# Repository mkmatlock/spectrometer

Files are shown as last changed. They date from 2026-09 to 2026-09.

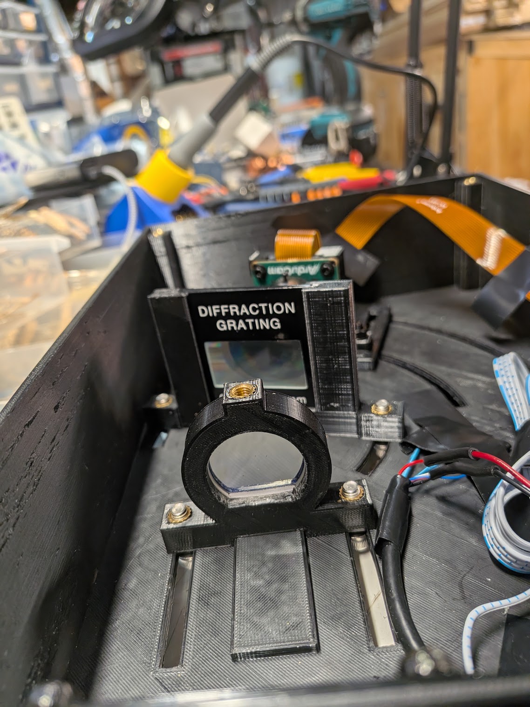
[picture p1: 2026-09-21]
images/build_axis.jpg

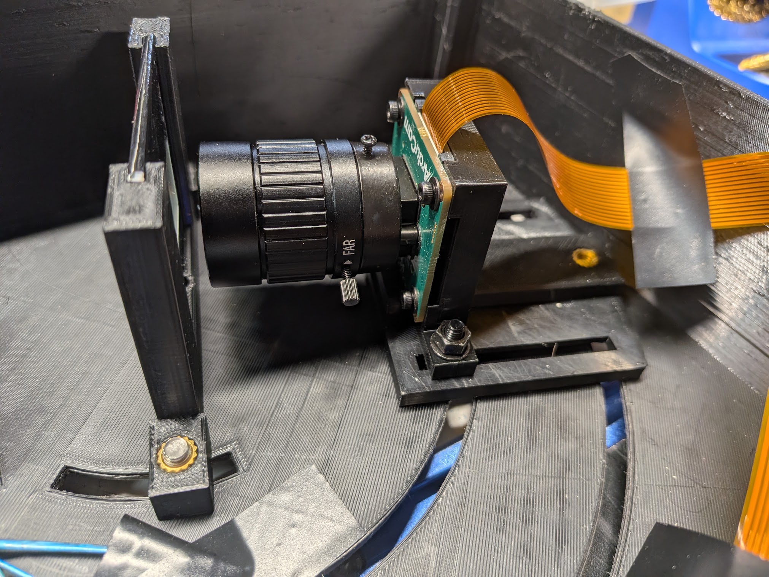
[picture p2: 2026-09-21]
images/build_camera.jpg

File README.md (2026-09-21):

# Raspberry pi configuration

First, we need to disable the activity light to eliminate a source of stray light and add an overlay to use the external LED as a power indicator.

Edit `/boot/firmware/config.txt`, find the `[all]` section heading and add:

```ini
[all]
dtparam=act_led_trigger=none
dtoverlay=gpio-led,gpio=26,label=power,trigger=default-on
```

Reboot with `sudo reboot` to apply.

Next, enable SPI and I2C in `sudo raspi-config` and reboot if prompted. The runtime user
needs access to the `spi`, `i2c`, and `gpio` groups.

Finally, hook up the waveshare device according to instructions [here](https://www.waveshare.com/wiki/3.5inch_Capacitive_Touch_LCD).

# Install the software

Fill out the dotenv:

```vi .env
HOST="RPI_IP_ADDRESS"
USER="RPI_USERNAME"
PORT="22"
```

# Run the spectrometer software

Install the distribution package on the Pi:

```sh
sudio ./setup.sh
```

This will start a systemd service spectrometer.service that will keep the spectrometer app running in the background at all times. 

## Raspberry Pi OS Lite hardware setup

The supplied drivers use BCM pins 27 (LCD reset), 25 (LCD data/command), 18
(backlight), 4 (touch interrupt), and 17 (touch reset), in addition to the SPI and
I2C bus pins. Wiring must match these assignments. Do not run another display
service or framebuffer driver that owns the same SPI device or GPIO pins.

Rendering passes Pygame RGB buffers directly to the LCD driver's RGB565
conversion. Camera acquisition starts by default. Use Raspberry
Pi OS Bookworm or later and install the updated dependencies with `setup.sh`.
Stop any separate camera server before starting this app; only one process can
own the camera.

```sh
python3 -m spectrometer --fps 5 --frame-averaging 3 --exposure-us 20000
```

Settings are loaded from `~/.spectrometer_config` on startup; the file is created
with defaults (5 fps, three-frame averaging, 4056×3040, automatic exposure) when absent. Camera settings,
calibration labels, and the sensor bounding box persist between runs. `--fps` and
`--frame-averaging`, and `--exposure-us` save new values; use `--auto-exposure` to restore automatic exposure.

Full-resolution IMX477 capture is
limited to about 10 fps; the requested rate is capped to the sensor mode's limit.
Fixed exposures are clamped to the sensor limits and frame period. Startup logs report the configured frame
period and first-frame exposure. Use `--no-camera` for touch-only diagnostics or
`--windowed --no-camera` for a desktop preview without Pi hardware.

## REST API

Open `http://<pi-address>:8000/` for the browser interface: review, rename,
delete, display modes, capture, and read-only settings. No frontend build or
internet connection is required. Capture requires the camera to be running.
The same service provides the API below.
`python3 -m spectrometer.server` runs the web interface and API without a camera.
Spectrum IDs are integer timestamps in milliseconds since the Unix epoch.

### GET /capture?name=<name>

Saves a spectrum locally and returns its ID as a JSON integer after saving.
Provide one URL-encoded name of 1–64 characters, for example
`/capture?name=My%20spectrum`.

Returns 400 for an invalid name, 409 when the camera is paused or busy, 503
when no camera is attached, or 500 on capture failure. A 504 means the request
timed out; the capture may still finish saving.

### GET /list

Returns a JSON array of saved spectra, newest first. Each entry contains `id`,
`name`, and `timestamp` formatted as `YYYY-MM-dd HH:mm:ss`. Returns `[]` when
there are no captures. Older unnamed captures use `Unnamed spectrum`;
unreadable files are skipped.
Metadata is kept in a rebuildable `.spectrometer_index.sqlite3` catalog beside
the captures. Existing captures are read once when first indexed; later lists do
not deserialize their raw camera images.

### GET /spectrum/<id>

Returns the full saved spectrum as JSON, including `filename`, name, timestamp,
instrument settings, saved calibration, intensities, sensor area, and image data.
Timestamps use ISO 8601; intensities are arrays; calibration pixel keys are
strings. Binary image data uses base64, with `dtype` and `shape` also included
for `averaged_camera_output` (the cropped BGR image). `spectrum_maximum` stores
the plot's intensity limit. Returns 404 for an unknown ID or 500 if the matching
spectrum data cannot be returned.
Only one full-spectrum transfer is processed at a time; another concurrent
transfer returns 503 to protect memory on the Pi Zero.

### DELETE /spectrum/<id>

Deletes the corresponding saved file. Returns 204 with an empty body on success,
404 for an unknown ID, or 500 if deletion fails.

### PATCH /spectrum/<id>

Renames a spectrum. Send `Content-Type: application/json` and `{"name":"New name"}`
(1–64 characters). Returns `{"id":123,"name":"New name"}`; the ID and recorded
data are preserved. Returns 400 for an invalid name, 404 for an unknown ID,
or 503 if another spectrum operation is in progress.

### GET /settings

Returns the current saved configuration and network status as a JSON object:

- `camera`: `frame_rate`, `frame_averaging`, `resolution`, and `exposure_us` (`"min"`/`"max"` follow the exposure limits; `null` means automatic).
- `calibration`: `scale` pixel/value pairs, `sensor_area`, and `channel_ranges`.
- `network`: `ip_address` and `wifi_ssid` (refreshed in the background).

## Touch diagnostics

```sh
python3 -m spectrometer --touch-debug
```

Touch and release each button. Logs show raw controller coordinates, mapped UI coordinates, releases, and placeholder button actions. Button centers are approximately `(82, 288)`, `(240, 288)`, and `(397, 288)`. If there are no touch logs, the controller is not reporting contacts; if mapped coordinates miss these locations, the panel needs a different coordinate mapping. Exit with Ctrl+C, then run `sudo systemctl start spectrometer` to restore the service.

Use `python3 -m spectrometer --performance-debug` to report rolling camera,
rendering, LCD, and metadata timings every five seconds without per-frame logs.

## Power button

Connect the momentary switch between GPIO 21 (physical pin 40) and GND. The app
enables the internal pull-up and debounces the switch. A short press toggles the
backlight and camera/UI activity on release. Hold for three seconds to open a
shutdown confirmation; Yes shuts down the Pi, and No returns to the application.
Run the updated `setup.sh` once to install the shutdown permission. The Pi remains
running. Pending captures are cancelled on pause; files already being written
finish saving. Press again to resume. This applies to the hardware UI.

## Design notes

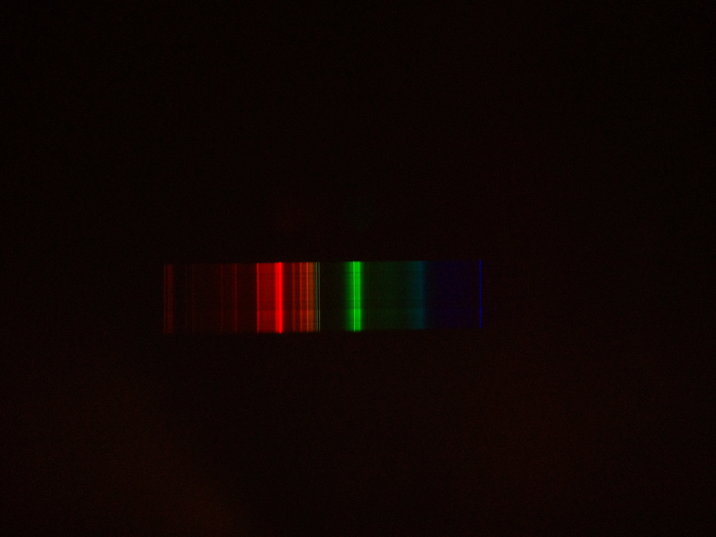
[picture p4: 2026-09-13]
images/cfl.png

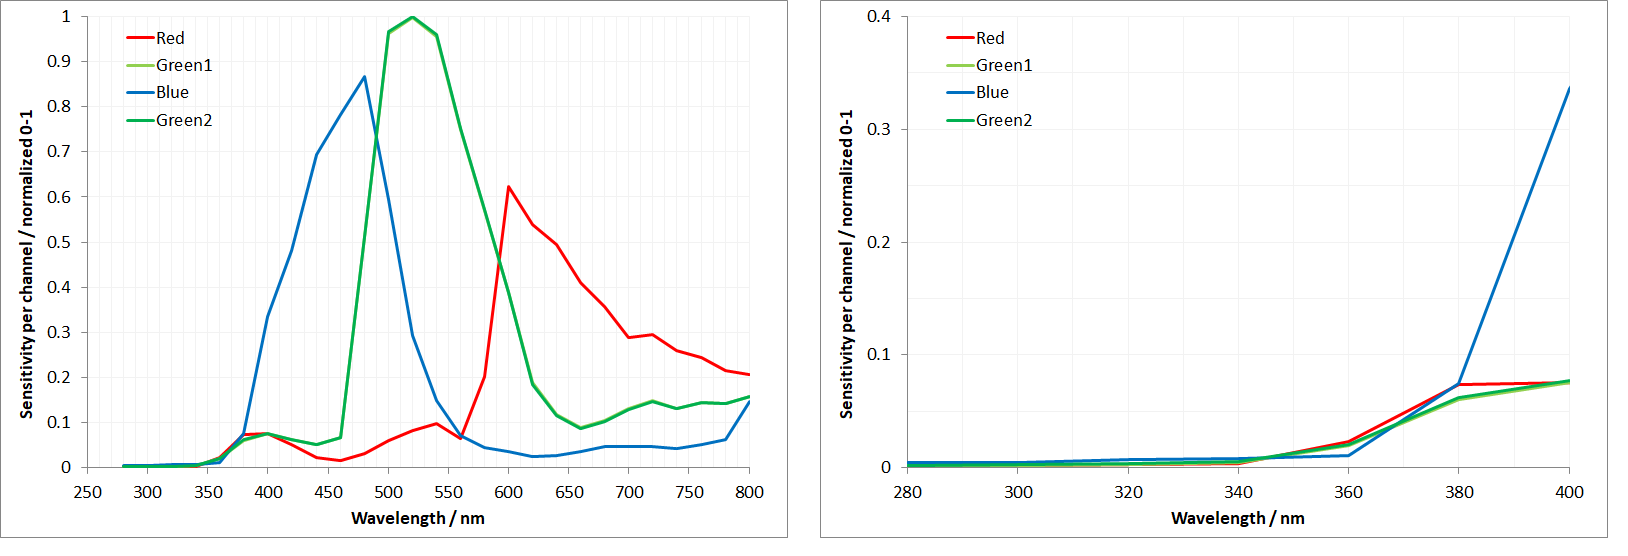
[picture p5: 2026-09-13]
images/IMX477_sensitivity.png

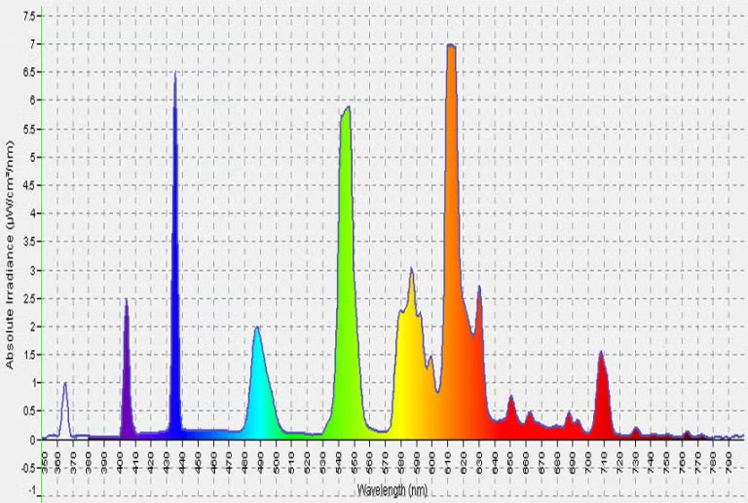
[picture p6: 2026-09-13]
images/reference.png

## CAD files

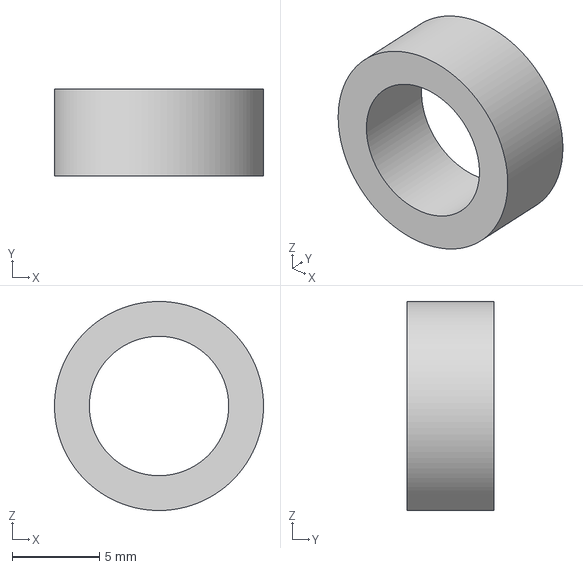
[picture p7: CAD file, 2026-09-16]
models/Slit Bushing.3mf
12.0 x 5.00 x 12.0 mm

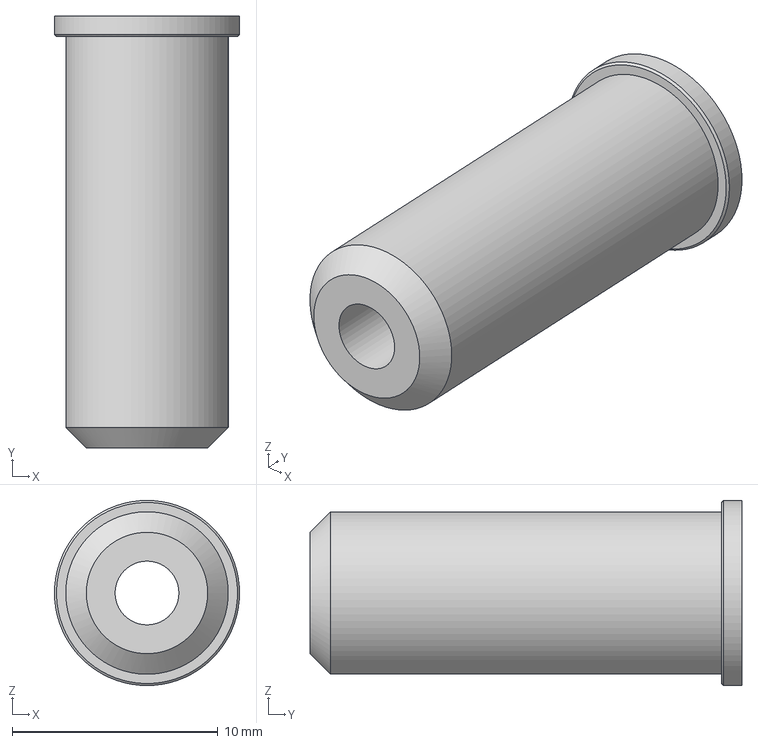
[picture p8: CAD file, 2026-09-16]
models/Slit Spring.3mf
9.00 x 21.0 x 9.00 mm

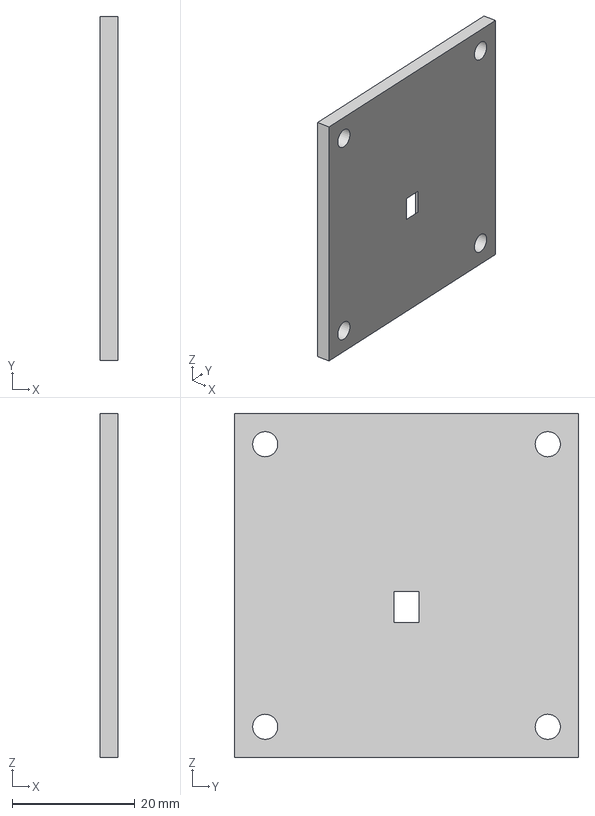
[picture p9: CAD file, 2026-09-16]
models/Slit Inner Cover.3mf
3.00 x 56.0 x 56.0 mm

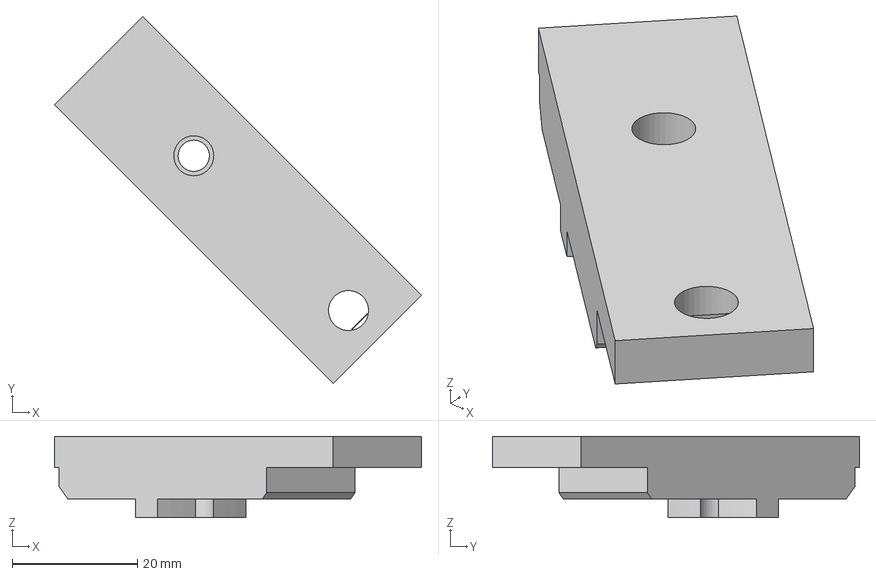
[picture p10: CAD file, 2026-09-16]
models/Camera Slide.3mf
58.7 x 58.7 x 13.0 mm

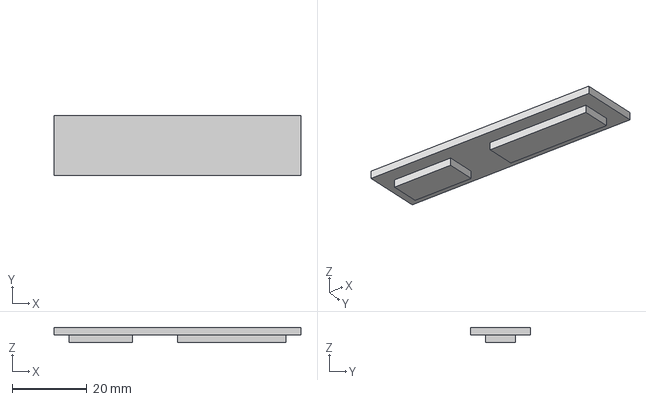
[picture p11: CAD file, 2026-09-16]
models/Port Cover.3mf
66.0 x 16.0 x 4.00 mm

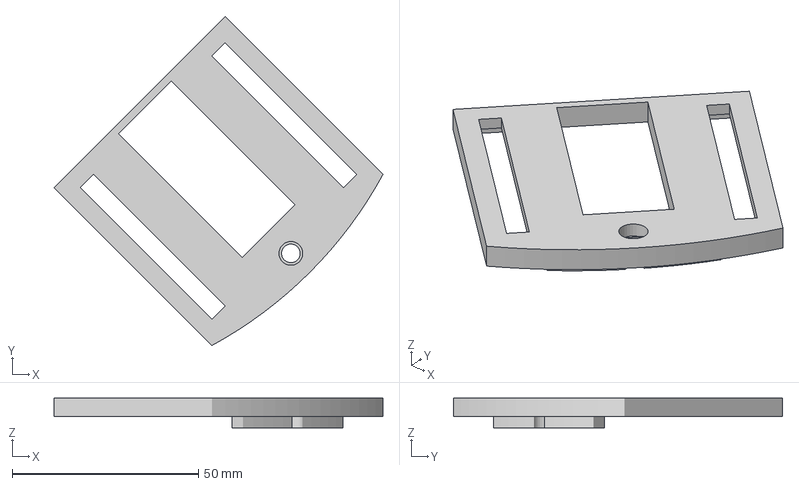
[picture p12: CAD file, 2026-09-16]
models/Camera Rotation.3mf
88.4 x 88.4 x 8.00 mm

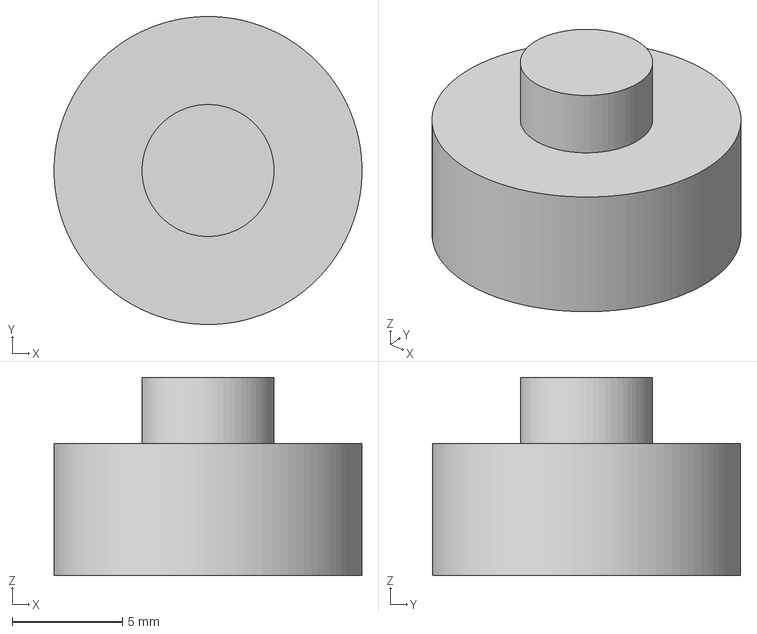
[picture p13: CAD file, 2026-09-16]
models/Foot.3mf
14.0 x 14.0 x 9.00 mm

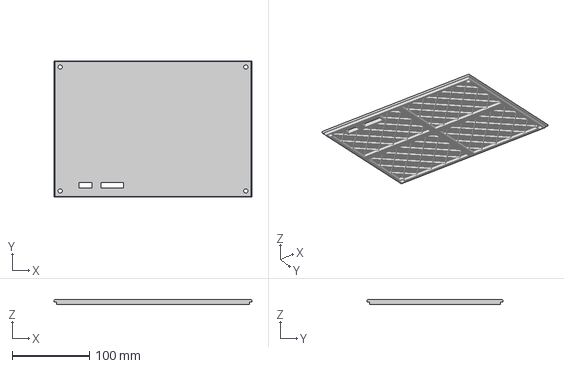
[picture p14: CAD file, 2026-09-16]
models/Lid.3mf
256.0 x 176.0 x 6.00 mm

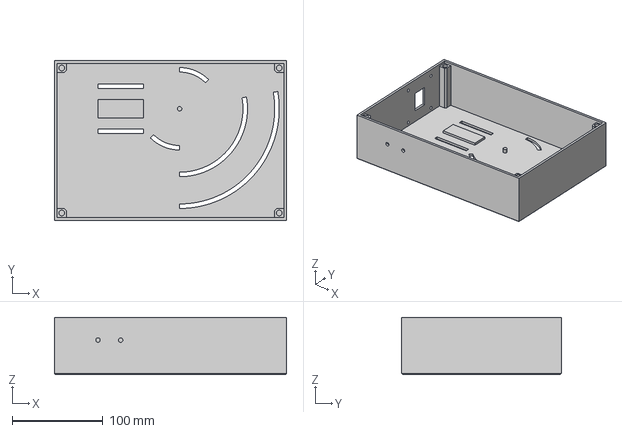
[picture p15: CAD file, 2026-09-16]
models/Enclosure.3mf
256.0 x 176.0 x 63.0 mm

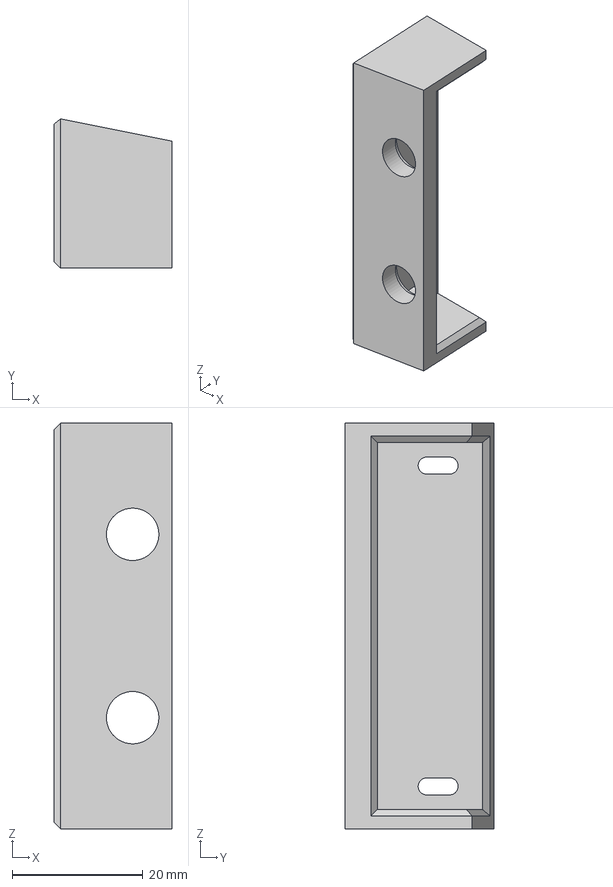
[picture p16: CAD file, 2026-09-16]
models/Slit Aperture.3mf
18.0 x 22.8 x 62.0 mm

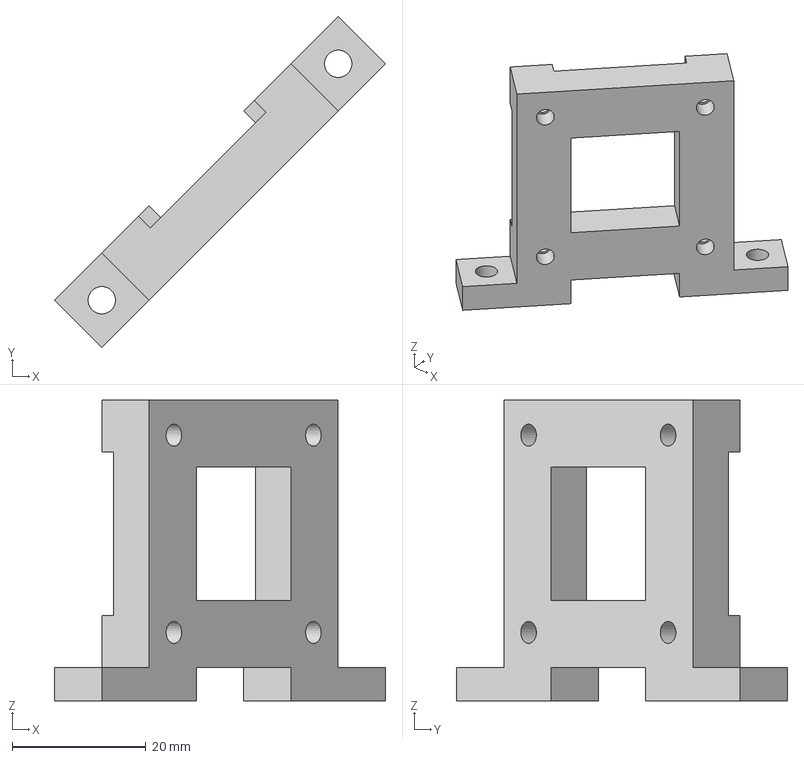
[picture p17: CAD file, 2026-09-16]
models/Camera Mount.3mf
49.5 x 49.5 x 45.0 mm

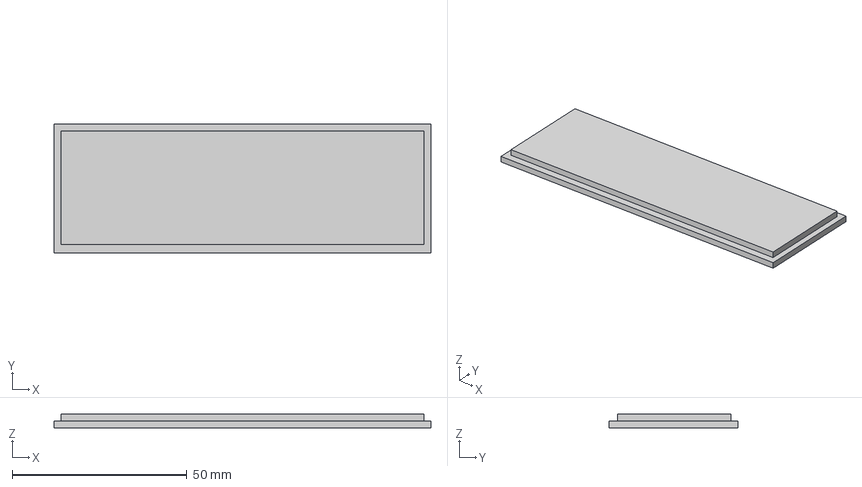
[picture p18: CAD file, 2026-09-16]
models/Interface Cover.3mf
108.0 x 37.0 x 4.00 mm

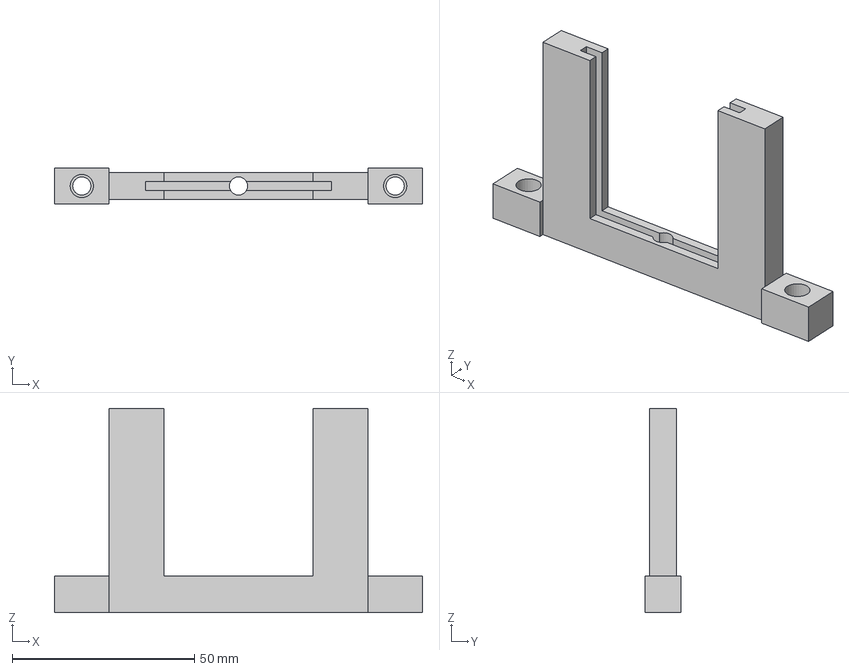
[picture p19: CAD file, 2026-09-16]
models/Diffractor.3mf
101.0 x 10.0 x 56.0 mm

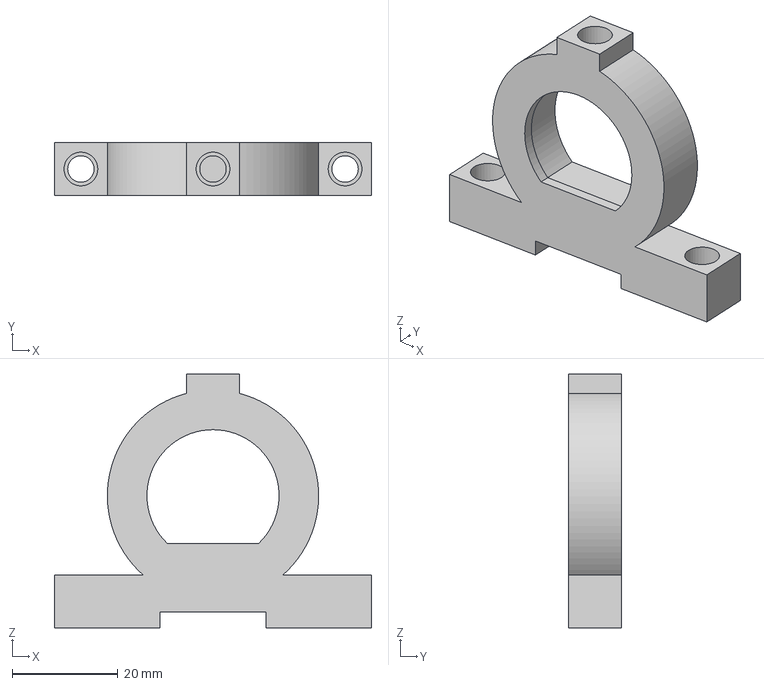
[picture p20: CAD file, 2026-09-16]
models/Collumnator.3mf
60.0 x 10.0 x 48.0 mm

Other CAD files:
models/Slit Stabilizer.3mf
models/Slit Mount.3mf
models/Microcontroller.3mf
models/Interface.3mf
schematics/PiZero.f3d
schematics/Spectrometer.f3z

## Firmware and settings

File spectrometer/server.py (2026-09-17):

"""Device-hosted spectrum viewer and spectrometer REST API."""

import argparse
from copy import deepcopy
import base64
from concurrent.futures import TimeoutError
from datetime import datetime
from pathlib import Path
import pickle
from contextlib import contextmanager
from http.client import HTTPConnection
from http.server import BaseHTTPRequestHandler, ThreadingHTTPServer
import json
import logging
import re
import threading
from urllib.parse import urlsplit, parse_qs

from .catalog import DuplicateSpectrumID, SpectrumCatalog, timestamp_id
from .capture import delete_capture, rename_capture, update_peak_label
from .settings import network_status


LOGGER = logging.getLogger(__name__)
WEB_DIRECTORY = Path(__file__).with_name('web')
STATIC_FILES = {
    '/': ('index.html', 'text/html; charset=utf-8'),
    '/app.js': ('app.js', 'text/javascript; charset=utf-8'),
    '/style.css': ('style.css', 'text/css; charset=utf-8'),
    '/spectrum-math.js': ('spectrum-math.js', 'text/javascript; charset=utf-8'),
    '/annotations.js': ('annotations.js', 'text/javascript; charset=utf-8'),
}
RESPONSE_CHUNK_SIZE = 64 * 1024


def json_value(value):
    if isinstance(value, datetime):
        return value.isoformat()
    if isinstance(value, bytes):
        return {'encoding': 'base64', 'data': base64.b64encode(value).decode('ascii')}
    if hasattr(value, 'tolist'):
        return value.tolist()
    raise TypeError(f'Cannot encode {type(value).__name__}')


def spectrum_response(path, record):
    """Full JSON representation of a saved spectrum."""
    result = dict(record, filename=path.name)
    image = record['averaged_camera_output']
    result['averaged_camera_output'] = {
        'encoding': 'base64', 'dtype': str(image.dtype), 'shape': list(image.shape),
        'data': base64.b64encode(image.tobytes()).decode('ascii')}
    return result


class APIHandler(BaseHTTPRequestHandler):
    timeout = 10

    def capture(self):
        query = parse_qs(urlsplit(self.path).query, keep_blank_values=True)
        names = query.get('name', [])
        if set(query) != {'name'} or len(names) != 1 or not 1 <= len(names[0].strip()) <= 64:
            self._respond({'error': 'Provide one name of 1–64 characters'}, 400)
            return
        camera = self.server.camera
        if camera is None:
            self._respond({'error': 'Camera unavailable'}, 503)
            return
        future = camera.request_api_capture(names[0].strip())
        if future is None:
            self._respond({'error': 'Camera paused or capture busy'}, 409)
            return
        try:
            _, record = future.result(timeout=120)
            self._respond(timestamp_id(record["timestamp"]))
        except TimeoutError:
            self._respond({'error': 'Capture timed out; it may still finish saving'}, 504)
        except (BrokenPipeError, ConnectionResetError):
            LOGGER.info('Capture saved; client disconnected')
        except Exception:
            LOGGER.exception('API capture failed')
            self._respond({'error': 'Capture failed'}, 500)

    def list(self):
        return self.server.catalog.list_api()

    def _find_spectrum(self, spectrum_id):
        path = self.server.catalog.find(spectrum_id)
        if path is None:
            return None
        try:
            with path.open('rb') as source:
                return path, pickle.load(source)
        except FileNotFoundError:
            self.server.catalog.remove(path.name)
            return None

    def spectrum(self, spectrum_id):
        if not self.server.raw_slots.acquire(blocking=False):
            self._respond({'error': 'Another spectrum transfer is in progress'}, 503)
            return
        try:
            try:
                found = self._find_spectrum(spectrum_id)
            except DuplicateSpectrumID:
                self._respond({'error': 'Spectrum ID is ambiguous'}, 409)
                return
            except Exception:
                LOGGER.exception('Cannot load spectrum %s', spectrum_id)
                self._respond({'error': 'Cannot read spectrum data'}, 500)
                return
            if found is None:
                self._respond({'error': 'Spectrum not found'}, 404)
                return
            path, record = found
            try:
                self._respond(spectrum_response(path, record))
            except (BrokenPipeError, ConnectionResetError):
                LOGGER.info('Client disconnected during download')
            except Exception:
                LOGGER.exception('Cannot read spectrum %s', path.name)
                self._respond({'error': 'Cannot read spectrum data'}, 500)
        finally:
            self.server.raw_slots.release()

    def delete_spectrum(self, spectrum_id):
        if not self.server.raw_slots.acquire(blocking=False):
            self._respond({'error': 'Another spectrum operation is in progress'}, 503)
            return
        try:
            self._delete_spectrum(spectrum_id)
        finally:
            self.server.raw_slots.release()

    def _delete_spectrum(self, spectrum_id):
        try:
            path = self.server.catalog.find(spectrum_id)
        except DuplicateSpectrumID:
            self._respond({'error': 'Spectrum ID is ambiguous'}, 409)
            return
        if path is None:
            self._respond({'error': 'Spectrum not found'}, 404)
            return
        try:
            delete_capture(path)
        except FileNotFoundError:
            self._respond({'error': 'Spectrum not found'}, 404)
        except OSError:
            LOGGER.exception('Cannot delete spectrum %s', path.name)
            self._respond({'error': 'Cannot delete spectrum'}, 500)
        else:
            self.server.catalog.remove(path.name)
            self.send_response(204)
            self.end_headers()

    def update_spectrum(self, spectrum_id):
        if self.headers.get_content_type() != 'application/json':
            self._respond({'error': 'Expected application/json'}, 415)
            return
        try:
            length = int(self.headers.get('Content-Length', '0'))
            if not 0 < length <= 4096 or self.headers.get('Transfer-Encoding'):
                raise ValueError('Invalid body length')
            payload = json.loads(self.rfile.read(length))
            if isinstance(payload, dict) and set(payload) == {'name'}:
                name = payload['name']
                if not isinstance(name, str) or not 1 <= len(name.strip()) <= 64:
                    raise ValueError('Invalid name')
                operation = 'rename'
            elif isinstance(payload, dict) and set(payload) == {'peak_label'}:
                annotation = payload['peak_label']
                if not isinstance(annotation, dict) or set(annotation) != {'pixel', 'label'}:
                    raise ValueError('Invalid peak label')
                pixel, label = annotation['pixel'], annotation['label']
                if type(pixel) is not int or (label is not None and
                        (not isinstance(label, str) or not 1 <= len(label.strip()) <= 64)):
                    raise ValueError('Invalid peak label')
                operation = 'label'
            else:
                raise ValueError('Invalid spectrum update')
        except (ValueError, UnicodeDecodeError, RecursionError):
            self._respond({'error': 'Provide a name of 1–64 characters or a peak_label '
                           'with an integer pixel and a label of 1–64 characters (null to delete)'}, 400)
            return
        if not self.server.raw_slots.acquire(blocking=False):
            self._respond({'error': 'Another spectrum operation is in progress'}, 503)
            return
        try:
            try:
                path = self.server.catalog.find(spectrum_id)
            except DuplicateSpectrumID:
                self._respond({'error': 'Spectrum ID is ambiguous'}, 409)
                return
            except Exception:
                LOGGER.exception('Cannot find spectrum %s for %s', spectrum_id, operation)
                self._respond({'error': 'Cannot read spectrum metadata'}, 500)
                return
            if path is None:
                self._respond({'error': 'Spectrum not found'}, 404)
                return
            try:
                if operation == 'rename':
                    result = {'name': rename_capture(path, name)}
                else:
                    try:
                        result = {'peak_labels': update_peak_label(path, pixel, label)}
                    except ValueError as exc:
                        self._respond({'error': str(exc)}, 400)
                        return
                # Usually a metadata-only check: the mutation already updates
                # SQLite. Also refresh this instance's in-memory fallback index.
                self.server.catalog.reconcile_paths([path])
            except FileNotFoundError:
                self.server.catalog.remove(path.name)
                self._respond({'error': 'Spectrum not found'}, 404)
                return
            except Exception:
                LOGGER.exception('Cannot %s spectrum %s', operation, path.name)
                self._respond({'error': 'Cannot ' + operation + ' spectrum'}, 500)
                return
            self._respond({'id': int(spectrum_id), **result})
        finally:
            self.server.raw_slots.release()

    def settings(self):
        from .config import SettingsStore
        store = self.server.settings_store
        if store is None:
            # Standalone API reads the same persistent configuration as the UI.
            store = SettingsStore()
        result = deepcopy(store.data)
        result['network'] = dict(self.server.network_settings)
        return result

    def static_file(self, path):
        filename, content_type = STATIC_FILES[path]
        try:
            data = (WEB_DIRECTORY / filename).read_bytes()
        except OSError:
            LOGGER.exception('Cannot read web asset %s', filename)
            self._respond({'error': 'Web application unavailable'}, 500)
            return
        self.send_response(200)
        self.send_header('Content-Type', content_type)
        self.send_header('Content-Length', str(len(data)))
        self.send_header('Cache-Control', 'no-cache')
        self.send_header('X-Content-Type-Options', 'nosniff')
        self.end_headers()
        self.wfile.write(data)

    def _respond(self, result, status=200):
        # Serialize before committing headers so encoding failures can still
        # return a normal error response.
        data = json.dumps(result, default=json_value).encode('utf-8')
        try:
            self.send_response(status)
            self.send_header('Content-Type', 'application/json')
            self.send_header('Content-Length', str(len(data)))
            self.send_header('Cache-Control', 'no-store')
            self.end_headers()
            # SocketWriter.write uses sendall: its timeout covers the entire
            # call, not just time without progress. Large images can take
            # longer than ten seconds over Wi-Fi. Bound each write so an
            # active transfer can continue while stalled clients still time out.
            view = memoryview(data)
            for offset in range(0, len(view), RESPONSE_CHUNK_SIZE):
                self.wfile.write(view[offset:offset + RESPONSE_CHUNK_SIZE])
        except OSError as exc:
            # Headers (and perhaps part of the body) have already been sent.
            # Never append a second HTTP response to the incomplete first one.
            self.close_connection = True
            LOGGER.warning('Response interrupted for %s: %s',
                           urlsplit(self.path).path, type(exc).__name__)

    def do_GET(self):
        path = urlsplit(self.path).path
        if path in STATIC_FILES:
            self.static_file(path)
            return
        if path == '/capture':
            self.capture()
            return
        endpoints = {'/list': self.list,
                     '/settings': self.settings}
        if path in endpoints:
            try:
                self._respond(endpoints[path]())
            except Exception:
                LOGGER.exception('API request failed for %s', path)
                self._respond({'error': 'Request failed'}, 500)
        elif match := re.fullmatch(r'/spectrum/([0-9]+)', path):
            self.spectrum(match.group(1))
        else:
            self._respond({'error': 'Not found'}, 404)

    def do_DELETE(self):
        path = urlsplit(self.path).path
        if match := re.fullmatch(r'/spectrum/([0-9]+)', path):
            self.delete_spectrum(match.group(1))
        else:
            self._respond({'error': 'Not found'}, 404)

    def do_PATCH(self):
        path = urlsplit(self.path).path
        if match := re.fullmatch(r'/spectrum/([0-9]+)', path):
            self.update_spectrum(match.group(1))
        else:
            self._respond({'error': 'Not found'}, 404)

    def log_message(self, message, *args):
        LOGGER.info('%s - %s', self.client_address[0], message % args)


@contextmanager
def running_server(host='0.0.0.0', port=8000, camera=None, capture_directory=None, settings_store=None):
    """Serve alongside the UI, releasing the socket when the application exits."""
    with ThreadingHTTPServer((host, port), APIHandler) as server:
        server.settings_store = settings_store
        server.camera = camera
        server.capture_directory = Path(capture_directory if capture_directory is not None else
                                        getattr(camera, "_capture_directory", Path.home()))
        server.catalog = SpectrumCatalog(server.capture_directory, persistent=True)
        # Index captures before accepting requests. Thereafter the
        # request path is a metadata-only SQLite query.
        server.catalog.reconcile_all()
        # Fault the small catalog and JSON encoder into memory before the
        # full-resolution camera begins consuming the single CPU.
        json.dumps(server.catalog.list_api())
        server.raw_slots = threading.BoundedSemaphore(1)
        server.network_settings = {'ip_address': 'Loading...', 'wifi_ssid': 'Loading...'}
        reconcile_stop = threading.Event()

        def reconcile_catalog():
            while not reconcile_stop.is_set():
                try:
                    address, ssid = network_status()
                    server.network_settings = {'ip_address': address, 'wifi_ssid': ssid}
                except Exception:
                    LOGGER.exception('Cannot read network status')
                if reconcile_stop.wait(30):
                    return
                try:
                    server.catalog.reconcile_all()
                except Exception:
                    LOGGER.exception('Background spectrum reconciliation failed')

        reconciler = threading.Thread(target=reconcile_catalog, name='spectrum-catalog', daemon=True)
        reconciler.start()
        worker = threading.Thread(target=server.serve_forever, name='spectrometer-api', daemon=True)
        worker.start()
        # Prime ThreadingHTTPServer's first handler thread before camera work
        # saturates the Pi Zero. Later external clients avoid a one-off delay.
        warm_host = '127.0.0.1' if server.server_address[0] in ('', '0.0.0.0') else server.server_address[0]
        connection = HTTPConnection(warm_host, server.server_address[1], timeout=5)
        try:
            connection.request('GET', '/list')
            response = connection.getresponse()
            response.read()
            if response.status != 200:
                LOGGER.warning('API warmup returned HTTP %s', response.status)
        except OSError:
            LOGGER.exception('API warmup failed')
        finally:
            connection.close()
        LOGGER.info('Spectrometer API listening on %s:%s', *server.server_address)
        try:
            yield server
        finally:
            server.shutdown()
            worker.join()
            reconcile_stop.set()
            reconciler.join()
            server.catalog.close()


def main():
    parser = argparse.ArgumentParser(description=__doc__)
    parser.add_argument('--host', default='0.0.0.0')
    parser.add_argument('--port', type=int, default=8000)
    args = parser.parse_args()
    if not 1 <= args.port <= 65535:
        parser.error('--port must be between 1 and 65535')
    import signal
    stopping = threading.Event()
    for signum in (signal.SIGINT, signal.SIGTERM):
        signal.signal(signum, lambda *_: stopping.set())
    logging.basicConfig(level=logging.INFO)
    with running_server(args.host, args.port):
        stopping.wait()


if __name__ == '__main__':
    main()

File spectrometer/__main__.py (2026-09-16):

"""Command-line entry point; hardware libraries are not required for --help."""

import argparse
import logging
from copy import deepcopy


def main():
    parser = argparse.ArgumentParser(description="Spectrometer UI on the SPI LCD and I2C touchscreen")
    parser.add_argument("--windowed", action="store_true", help="Open a desktop preview")
    parser.add_argument("--touch-debug", action="store_true",
                        help="Log raw/mapped touch coordinates and button actions")
    parser.add_argument("--fps", type=float, help="Save requested camera fps (default: stored value, initially 5)")
    parser.add_argument("--frame-averaging", type=int,
                        help="Save rolling frame count (default: stored value, initially 3)")
    exposure = parser.add_mutually_exclusive_group()
    exposure.add_argument("--exposure-us", type=int, help="Save manual exposure in microseconds")
    exposure.add_argument("--auto-exposure", action="store_true", help="Save automatic exposure mode")
    parser.add_argument("--no-camera", action="store_true", help="Run the UI without camera acquisition")
    parser.add_argument("--performance-debug", action="store_true",
                        help="Log camera processing and LCD transfer times")
    args = parser.parse_args()
    logging.basicConfig(level=logging.DEBUG if args.touch_debug else logging.INFO,
                        format="%(asctime)s %(levelname)s %(name)s: %(message)s")
    if args.performance_debug:
        logging.getLogger("spectrometer.performance").setLevel(logging.DEBUG)

    from .ui import SpectrometerUI
    from .camera import CameraSettings, CameraStream
    from .config import SettingsStore
    from .server import running_server

    try:
        store = SettingsStore()
        overrides = {}
        if args.fps is not None:
            overrides['frame_rate'] = args.fps
        if args.frame_averaging is not None:
            overrides['frame_averaging'] = args.frame_averaging
        if args.exposure_us is not None or args.auto_exposure:
            overrides['exposure_us'] = args.exposure_us
        store.update(camera=overrides)
        settings = CameraSettings(**store.data['camera'], roi=store.data['calibration']['sensor_area'])
    except (OSError, ValueError) as exc:
        parser.error(str(exc))

    camera = None if args.no_camera else CameraStream(settings)
    with running_server(camera=camera, settings_store=store):
        SpectrometerUI(fullscreen=not args.windowed,
                       camera_settings=deepcopy(store.data['camera']),
                       calibration_settings=deepcopy(store.data['calibration']),
                       on_calibration_changed=lambda values: store.update(calibration=values),
                       on_camera_settings_changed=lambda camera_values, calibration=None:
                       store.update(camera=camera_values, calibration=calibration),
                       camera=camera).run()


if __name__ == "__main__":
    main()

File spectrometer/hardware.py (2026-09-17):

"""Bridge the supplied SPI LCD and I2C touchscreen drivers to the UI."""

from contextlib import ExitStack
import logging
import queue
import threading
import time

from .performance import PerformanceMetrics


LOGGER = logging.getLogger(__name__)
METRICS = PerformanceMetrics('lcd')


class LCDBackend:
    """Own the hardware resources; importing this module needs no Pi libraries."""

    def __init__(self):
        self._last_touch = None
        self._power_down = False
        self._power_started = None
        self._power_held = False
        self._present_error = None

    def __enter__(self):
        from .st7796 import st7796
        from .ft6336u import ft6336u

        self._resources = ExitStack()
        try:
            self.display = st7796()
            self._resources.callback(self.display.close)
            self._present_queue = queue.Queue(maxsize=1)
            self._present_error = None
            self._present_stop = object()
            self._present_thread = threading.Thread(target=self._present_worker,
                                                    name='lcd-present', daemon=True)
            self._present_thread.start()
            self._resources.callback(self._stop_presenter)
            self.touch = ft6336u()
            self._resources.callback(self.touch.close)
            from gpiozero import Button

            # Momentary switch between BCM21 (physical pin 40) and ground.
            self.power_button = Button(21, pull_up=True, bounce_time=0.05)
            self._resources.callback(self.power_button.close)
        except BaseException:
            self._resources.close()
            raise
        return self

    def __exit__(self, *exc):
        return self._resources.__exit__(*exc)

    def power_event(self):
        """Short press on release, or one hold event after three seconds."""
        down = self.power_button.is_pressed
        now = time.monotonic()
        event = None
        if down and not self._power_down:
            self._power_started = now
            self._power_held = False
        if self._power_down or down:
            if not self._power_held and now - self._power_started >= 3:
                event = 'hold'
                self._power_held = True
            elif not down and not self._power_held:
                event = 'short'
        self._power_down = down
        return event

    def set_screen_active(self, active):
        self.display.bl_DutyCycle(100 if active else 0)

    @staticmethod
    def _merge_regions(first, second, full_rect):
        if first is None or second is None:
            return None
        result = []
        for rect in (*first, *second):
            clipped = rect.clip(full_rect)
            if clipped.width and clipped.height and clipped not in result:
                result.append(clipped)
        return result

    def _prepare(self, surface, regions):
        import pygame
        rects = [surface.get_rect()] if regions is None else list(regions)
        patches = []
        for rect in rects:
            patch = surface.subsurface(rect)
            width, height = patch.get_size()
            rgb = pygame.surfarray.pixels3d(patch).swapaxes(0, 1)
            try:
                pixels = self.display.prepare_array(width, height, rgb, mirror=True)
            finally:
                del rgb
            patches.append((rect.x, rect.y, width, height, pixels, regions is None))
        return patches

    def _present_worker(self):
        while True:
            task = self._present_queue.get()
            try:
                if task is self._present_stop:
                    return
                _, patches = task
                for patch in patches:
                    self.display.write_prepared(*patch)
            except Exception as exc:
                self._present_error = exc
                LOGGER.exception('LCD presentation failed')
            finally:
                self._present_queue.task_done()

    def _stop_presenter(self):
        self._present_queue.join()
        self._present_queue.put(self._present_stop)
        self._present_thread.join()

    def _queue_present(self, surface, regions):
        wanted = None if regions is None else list(regions)
        while True:
            try:
                old_regions, _ = self._present_queue.get_nowait()
            except queue.Empty:
                break
            else:
                self._present_queue.task_done()
                wanted = self._merge_regions(old_regions, wanted, surface.get_rect())
        patches = self._prepare(surface, wanted)
        self._present_queue.put_nowait((wanted, patches))

    def present(self, surface, regions=None):
        started = time.monotonic()
        if self._present_error is not None:
            raise RuntimeError('LCD presentation failed') from self._present_error
        pixels = sum(rect.width * rect.height for rect in
                     ([surface.get_rect()] if regions is None else regions))
        self._queue_present(surface, regions)
        elapsed_ms = (time.monotonic() - started) * 1000
        METRICS.add('transfer_ms', elapsed_ms)
        METRICS.add('pixels', pixels)

    def read_touch(self):
        started = time.monotonic()
        self.touch.read_touch_data()
        count, coordinates = self.touch.get_touch_xy()
        METRICS.add('touch_read_ms', (time.monotonic() - started) * 1000)
        if not count:
            if self._last_touch is not None:
                LOGGER.debug("Touch released")
            self._last_touch = None
            return None
        # Undo the driver's native X mirror before using it as landscape Y.
        # Physical button samples confirm UI = (479 - raw_y, raw_x).
        point = coordinates[0]
        position = (479 - point["y"], 319 - point["x"])
        sample = (count, point["x"], point["y"])
        if sample != self._last_touch:
            LOGGER.debug("Touch count=%s raw=(%s, %s) UI=%s", count,
                         319 - point["x"], point["y"], position)
        self._last_touch = sample
        # Do not turn an invalid sample into a press on a screen edge.
        if not (0 <= position[0] < 480 and 0 <= position[1] < 320):
            return None
        return position

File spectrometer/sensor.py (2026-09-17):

"""Small full-sensor preview and sensor-coordinate ROI selection."""

import pygame


class SensorSelection:
    def __init__(self, preview, roi):
        pixels, size, self.resolution = preview
        self.bounds = (0, 0, *self.resolution)
        self.image = pygame.transform.flip(pygame.image.frombuffer(pixels, size, 'RGB'), True, False)
        self.rect = self.image.get_rect(center=(240, 128))
        self.roi = tuple(roi)
        self.start = None
        self.message = ''

    def point(self, position):
        x = min(1, max(0, (position[0] - self.rect.left) / self.rect.width))
        y = min(1, max(0, (position[1] - self.rect.top) / self.rect.height))
        x0, y0, x1, y1 = self.bounds
        return (x0 + round((1 - x) * (x1 - x0) / 2) * 2,
                y0 + round(y * (y1 - y0) / 2) * 2)

    def drag(self, position):
        end = self.point(position)
        self.roi = (min(self.start[0], end[0]), min(self.start[1], end[1]),
                    max(self.start[0], end[0]), max(self.start[1], end[1]))
        self.message = ''

    def draw(self, surface, font):
        surface.blit(self.image, self.rect)
        x0, y0, x1, y1 = self.roi
        bx0, by0, bx1, by1 = self.bounds
        width, height = bx1 - bx0, by1 - by0
        left = self.rect.left + round((bx1 - x1) * self.rect.width / width)
        top = self.rect.top + round((y0 - by0) * self.rect.height / height)
        right = self.rect.left + round((bx1 - x0) * self.rect.width / width)
        bottom = self.rect.top + round((y1 - by0) * self.rect.height / height)
        pygame.draw.rect(surface, '#ffd166', (left, top, max(1, right-left), max(1, bottom-top)), 2)
        if self.message:
            text = font.render(self.message, True, '#ffd166', '#111820')
            surface.blit(text, (8, 8))

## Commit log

2026-09-13 Added hardware drivers, README for setup, and install/systemd scripts.
    [PiZero.f3d]
2026-09-13 Added camera capture
2026-09-13 Changed camera metadata location
2026-09-13 Added power button pause functionality
2026-09-13 Added placeholders for calibration modes
2026-09-13 Added filtering to the review page
2026-09-13 Make the camera display match the spectrum display X axis
2026-09-13 Added calibration curves image
2026-09-13 Added additional calibration data
2026-09-13 Added ROI selection calibration
2026-09-13 Added scaling of X-axis when calibrated
2026-09-13 Added shutdown command on power button long press
2026-09-13 Added instructions to enable the power LED
2026-09-14 Store calibration data with each capture, to ensure data can be displayed appropriately
2026-09-16 Added models and schematics to github
    [Camera Mount.3mf, Camera Rotation.3mf, Camera Slide.3mf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]
2026-09-16 Added black body curve fitting and temperature estimation
2026-09-16 Added channel notch filter calibration
2026-09-16 Added calibration reset buttons
2026-09-16 Added frame averaging to reduce noise
    [__main__.py, camera.py, config.py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]
2026-09-16 Added a bushing to the spring housing
    [Slit Bushing.3mf]
2026-09-17 Calibration scale applies to image used for calibration
2026-09-17 Reorganize buttons on Scale activity
2026-09-17 Added reset button to calibrate->sensor task
2026-09-21 Added slower frame rates and more exposure time options
